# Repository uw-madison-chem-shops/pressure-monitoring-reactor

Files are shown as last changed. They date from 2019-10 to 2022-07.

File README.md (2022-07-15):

# A Gas Uptake/Evolution Reactor for Monitoring Gas-Liquid Chemical Transformations in Parallel

This repository contains supplemental material for the paper "A Gas Uptake/Evolution Reactor for Monitoring Gas-Liquid Chemical Transformations in Parallel". 
[doi:10.1063/5.0043007](https://doi.org/10.1063/5.0043007)
Please read the manuscript for more context about these materials.

## Repository

This repository is being mirrored to several version control systems in an attempt to ensure maximum avaliability.

| name | url |
| --- | --- |
| Chem (primary) | https://git.chem.wisc.edu/stahl-group/pressure-monitoring-reactor |
| GitHub | https://github.com/uw-madison-chem-shops/pressure-monitoring-reactor | 
| GitLab | https://gitlab.com/uw-madison-chem-shops/pressure-monitoring-reactor |

## Reactor Cell

The reactor cell is made up of three pieces:

1. body
2. arms
3. clamp ring

CAD drawings for each of these pieces can be found in the `reactor-cell` folder.
These drawings were created using SolidWorks CAD software, and a copy of SolidWorks will be required to open or manipulate them.
For convinience, machinist drawings as PDFs are also shared.

Refer to the Supplementary Material PDF associated with the main publication for assembly instructions.

## Heating Block

The heating block is made up of six pieces:

1. main block
2. sidebars
3. cooling tube
4. side insulation
5. top insulation
6. end insulation

CAD drawings for each of these pieces can be found in the `heating block` folder.
These drawings were created using SolidWorks CAD software, and a copy of SolidWorks will be required to open or manipulate them.
For convinience, machinist drawings as PDFs are also shared.

Refer to the Supplementary Material PDF associated with the main publication for assembly instructions.

## Manifold

A CAD drawing of the gas distribution manifold can be found in the `manifold` folder.
This drawing was created using AutoCAD software, and software capable of reading `.dwg` files is required to open or manipulate it.
For convinience, a machinist drawing as PDF is also shared.

Refer to the Supplementary Material PDF associated with the main publication for assembly instructions.

## Electronics

CAD drawings describing the panel cutouts for the electronics box can be found in the `electronics` folder.

## Software

Custom software developed for this reactor can be found in the `software` folder.
This is separated out into the director and interface, as described in the Supplementary Material PDF.
Further instructions for installing this software onto the Raspberry Pi can be found in the `software` folder.

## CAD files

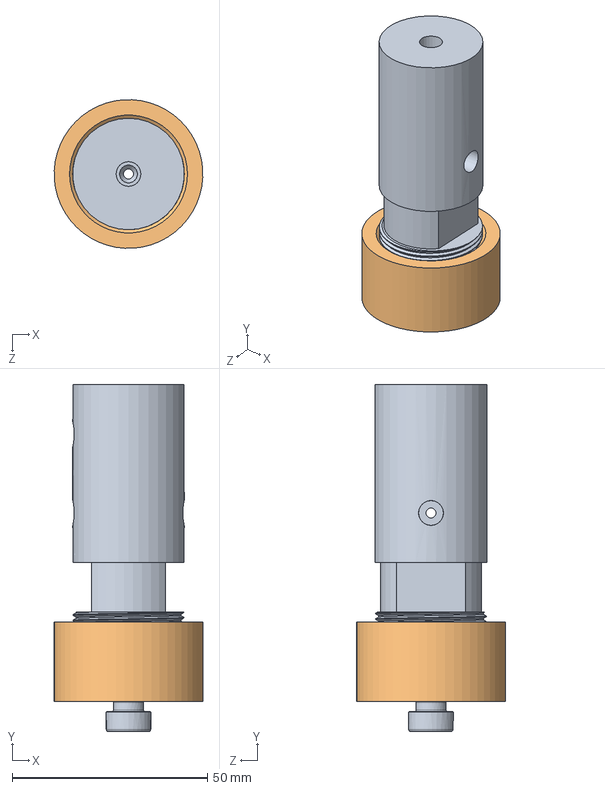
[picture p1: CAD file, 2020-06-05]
reactor-cell/Assem1.SLDASM
38.1 x 88.9 x 38.1 mm
clampring1

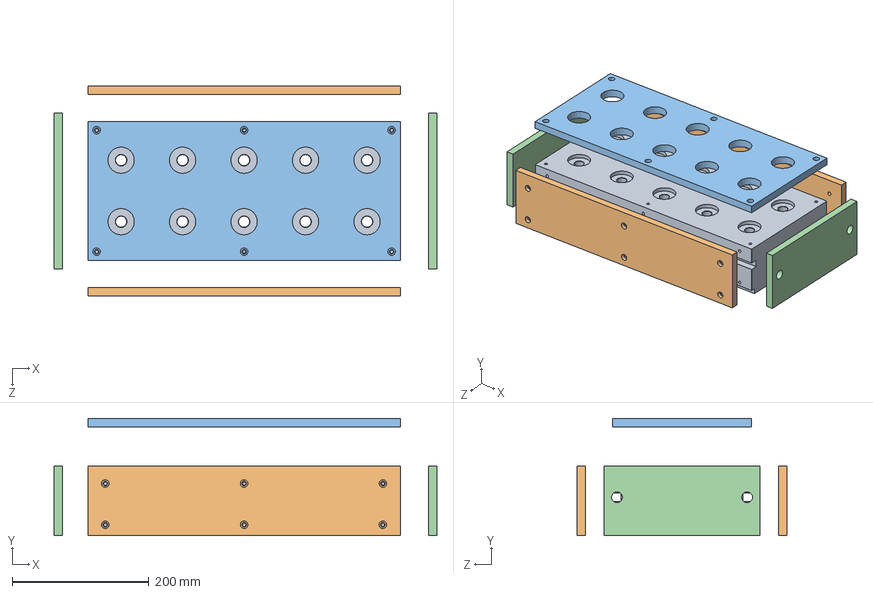
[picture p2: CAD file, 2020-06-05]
heating-block/htrblockassem1.SLDASM
560.6 x 171.5 x 307.7 mm
heatblk1
sideinsul1 x 2
topinsul1
endisul1 x 2

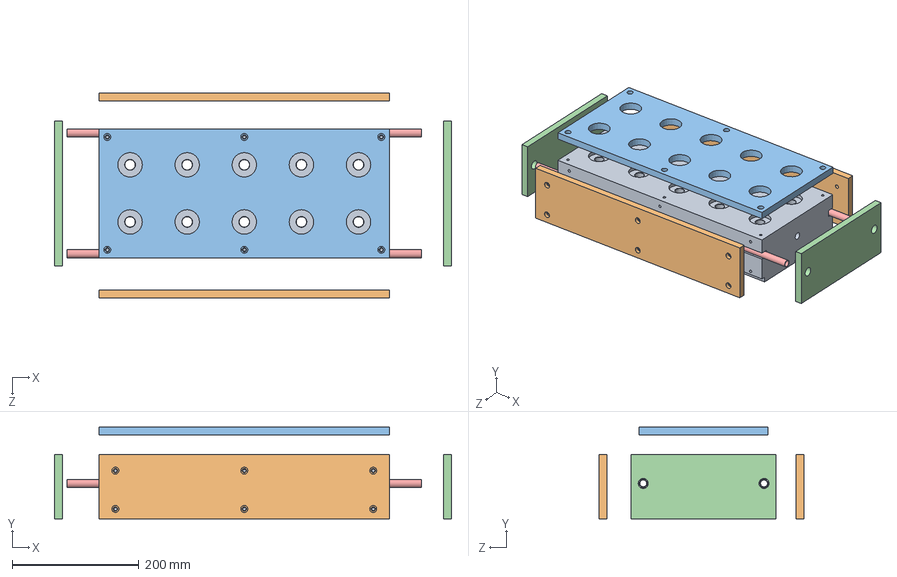
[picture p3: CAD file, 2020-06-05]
heating-block/htrblockassem2.SLDASM
625.6 x 145.0 x 323.7 mm
heatblk1
sideinsul1 x 2
topinsul1
endisul1 x 2
cooltube1 x 2

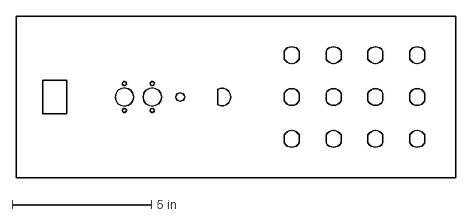
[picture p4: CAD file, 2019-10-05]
electronics/front.dxf
15.8 x 5.80 in

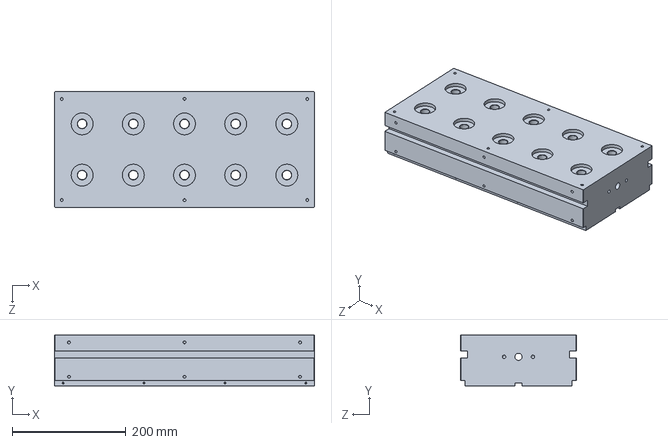
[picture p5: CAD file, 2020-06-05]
heating-block/heatblk1.SLDPRT
457.2 x 88.9 x 203.2 mm

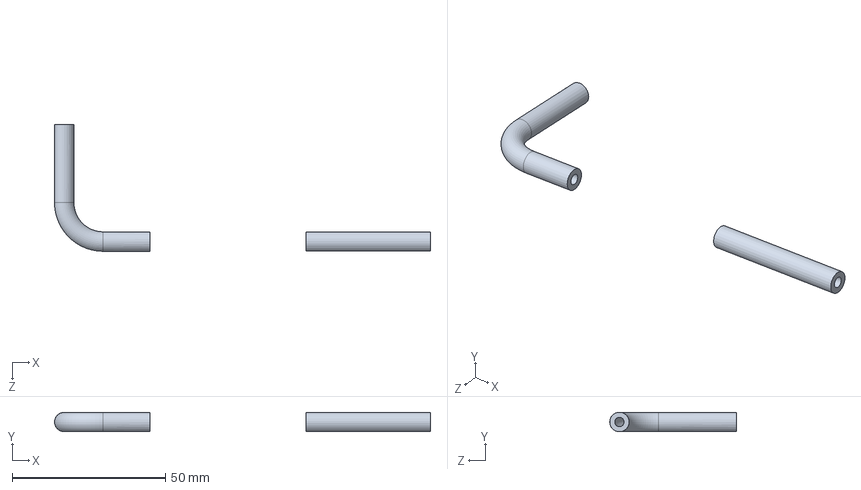
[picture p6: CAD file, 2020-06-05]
reactor-cell/reactortubes1.SLDPRT
122.6 x 6.35 x 41.3 mm

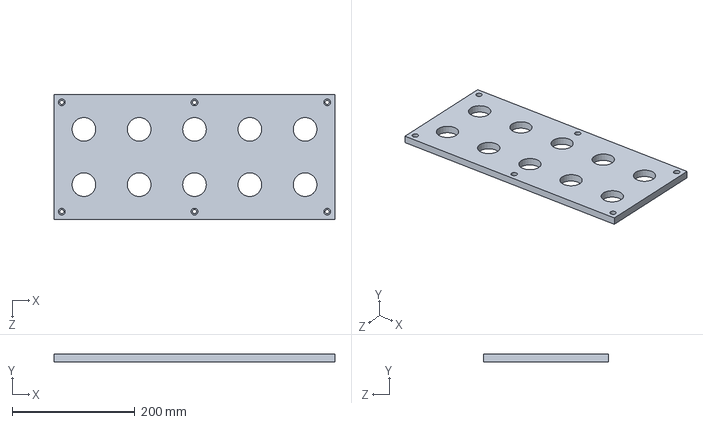
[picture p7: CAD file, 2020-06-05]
heating-block/topinsul1.SLDPRT
457.2 x 12.7 x 203.2 mm

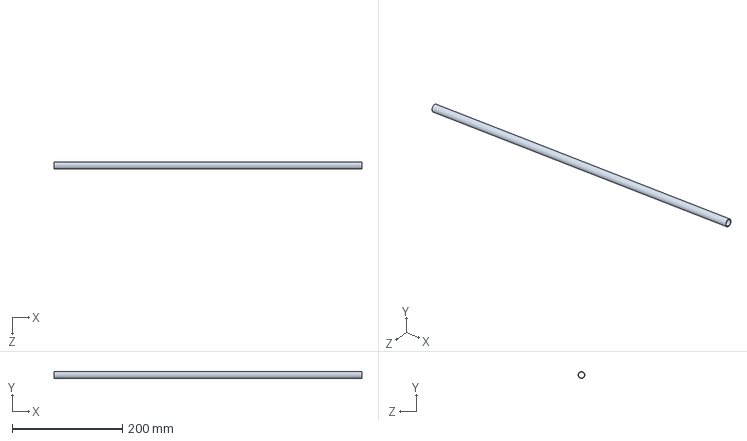
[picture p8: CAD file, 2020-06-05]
heating-block/cooltube1.SLDPRT
558.8 x 12.7 x 12.7 mm

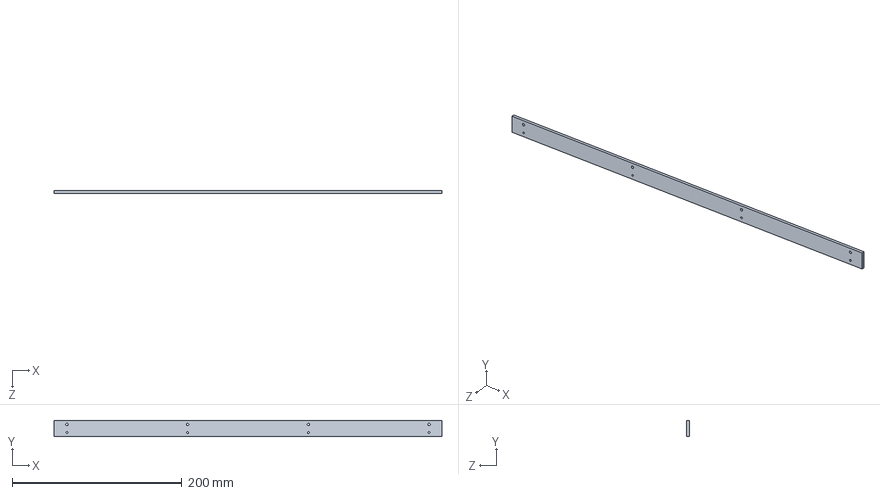
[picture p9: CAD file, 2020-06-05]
heating-block/sidebar1.SLDPRT
457.2 x 19.1 x 3.17 mm

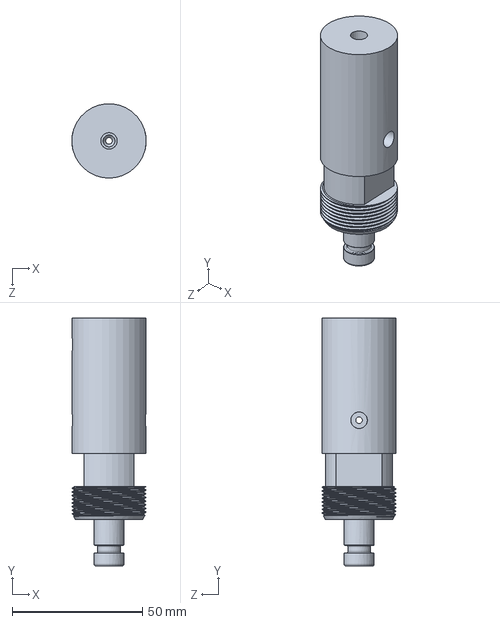
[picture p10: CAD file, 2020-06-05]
reactor-cell/body1.SLDPRT
28.6 x 95.2 x 28.5 mm

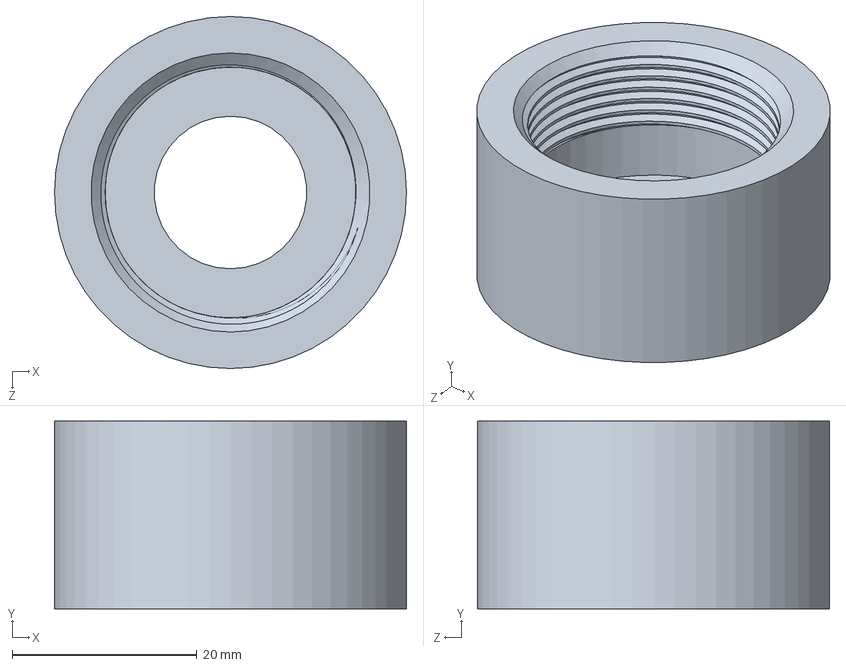
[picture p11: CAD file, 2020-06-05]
reactor-cell/clampring1.SLDPRT
38.1 x 20.3 x 38.1 mm

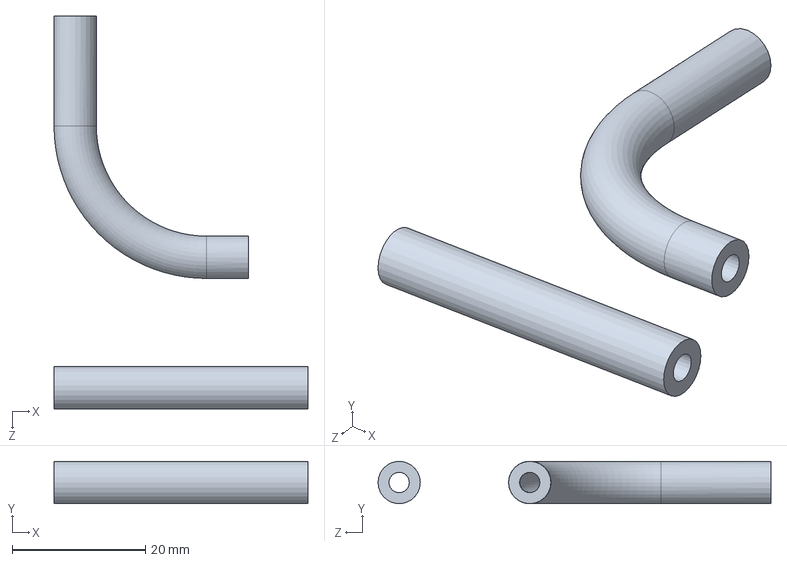
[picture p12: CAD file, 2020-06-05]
reactor-cell/tubes1.SLDPRT
38.1 x 6.35 x 59.0 mm

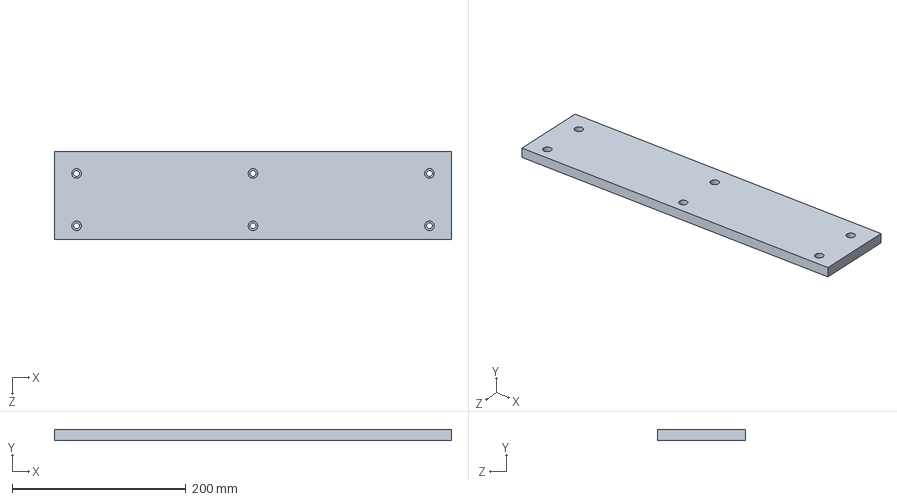
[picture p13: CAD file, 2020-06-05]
heating-block/sideinsul1.SLDPRT
457.2 x 12.7 x 101.6 mm

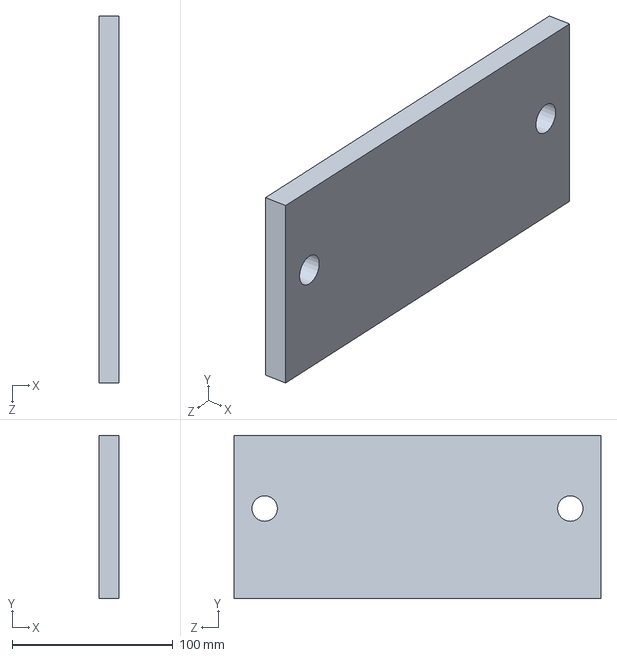
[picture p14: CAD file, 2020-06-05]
heating-block/endisul1.SLDPRT
12.7 x 101.6 x 228.6 mm

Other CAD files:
manifold/Manifold - Apr 13 2020 - CAS.dwg
reactor-cell/CAS Design 4.dwg
heating-block/Heating Block and Stir Plate - Jun 14 2019 - CAS Block Estimates.dwg
heating-block/heatblk1.SLDDRW
heating-block/sidebar1.SLDDRW
reactor-cell/Assem1.SLDDRW
reactor-cell/body1.SLDDRW
reactor-cell/clampring1.SLDDRW
reactor-cell/reactortubes1.SLDDRW
reactor-cell/tubes1.SLDDRW

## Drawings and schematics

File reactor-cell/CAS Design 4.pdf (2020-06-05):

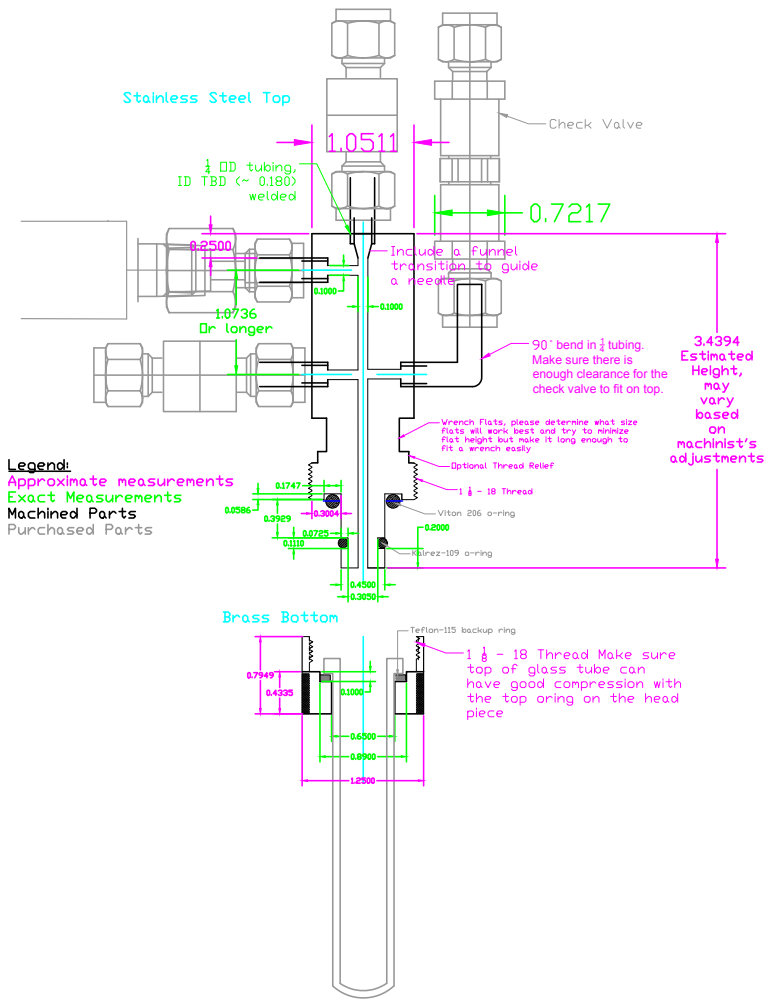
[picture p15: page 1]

˚ bend in 14 tubing. Make sure there is enough clearance for the check valve to fit on top.

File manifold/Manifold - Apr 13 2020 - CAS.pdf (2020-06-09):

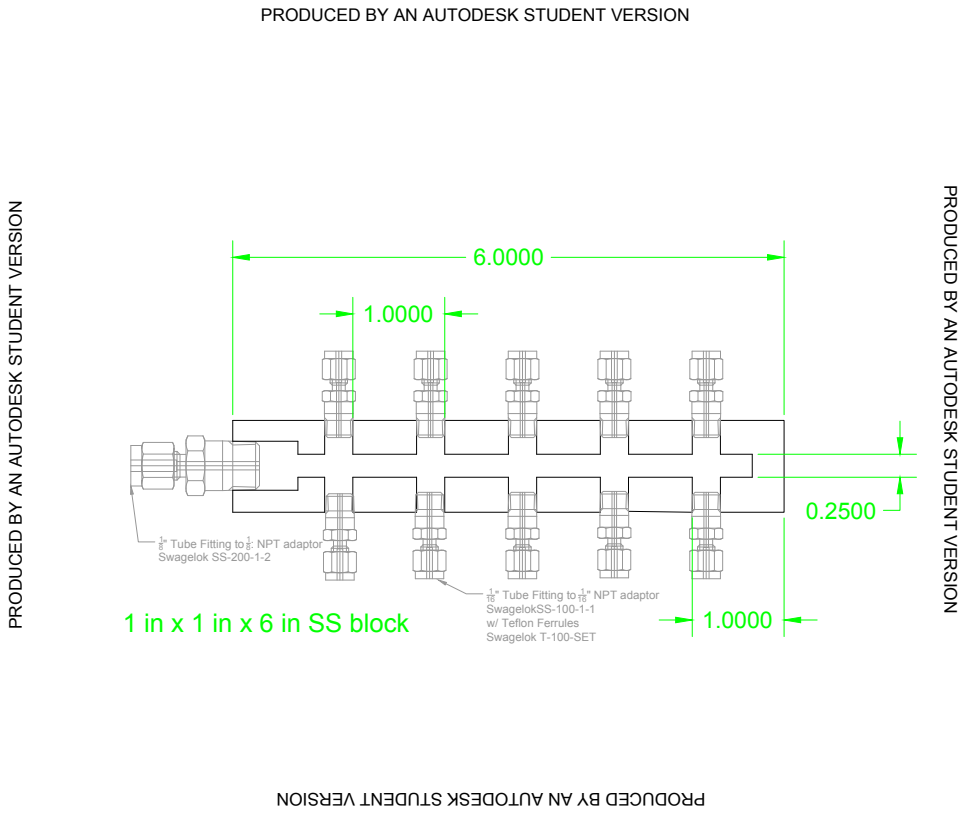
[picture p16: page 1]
18" Tube Fitting to 18: NPT adaptor Swagelok SS-200-1-2; 116" Tube Fitting to 116" NPT adaptor SwagelokSS-100-1-1 w/ Teflon Ferrules Swagelok T-100-SET 1 in x 1 in x 6 in SS block

PRODUCED BY AN AUTODESK STUDENT VERSION

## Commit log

2019-10-13 button actions
2020-04-14 add transducer calibration files
2020-06-05 rename folders
    [front.dxf]
2020-06-09 heating block description
2021-01-11 add simple-pid
2022-07-15 poll temperature
2024-03-15 record tare pressure
